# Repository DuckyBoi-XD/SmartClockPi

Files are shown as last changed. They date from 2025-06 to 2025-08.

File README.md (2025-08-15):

A Raspberry Pi Zero 2 W based smart clock with touchscreen display, environmental sensing, and internet weather integration.

## KiCad Stuff

This project uses KiCad for PCB design. The files are located in the `PCB/` directory. You can open them with KiCad to view the schematics and PCB layout. These are the screenshots of the PCB and schematics:

### PCB Design

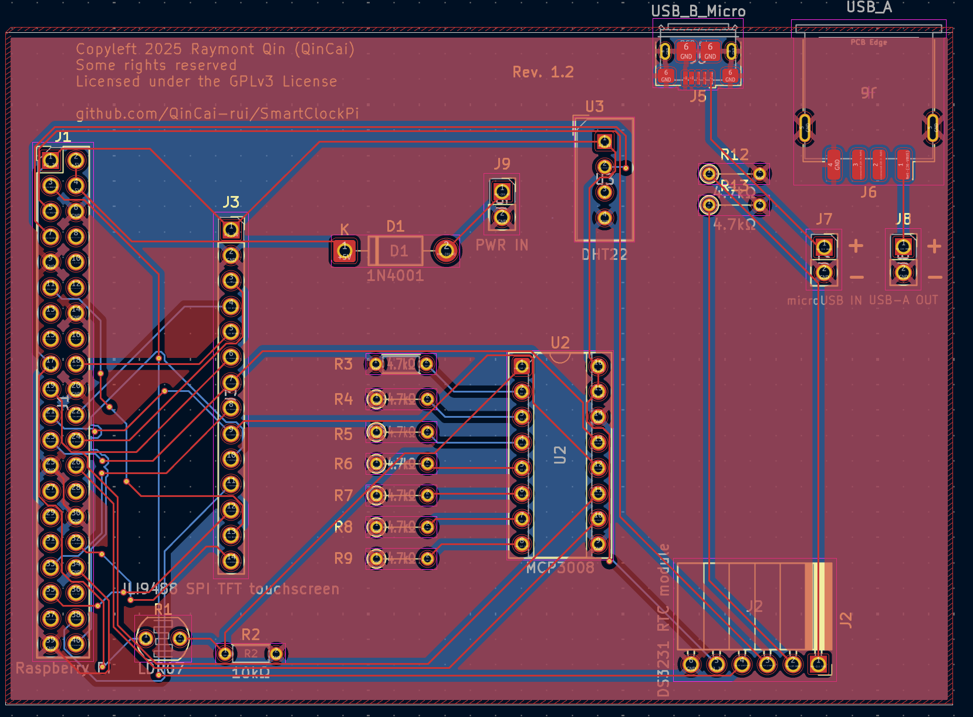
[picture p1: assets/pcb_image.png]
PCB image


### PCB rendering



### Schematics

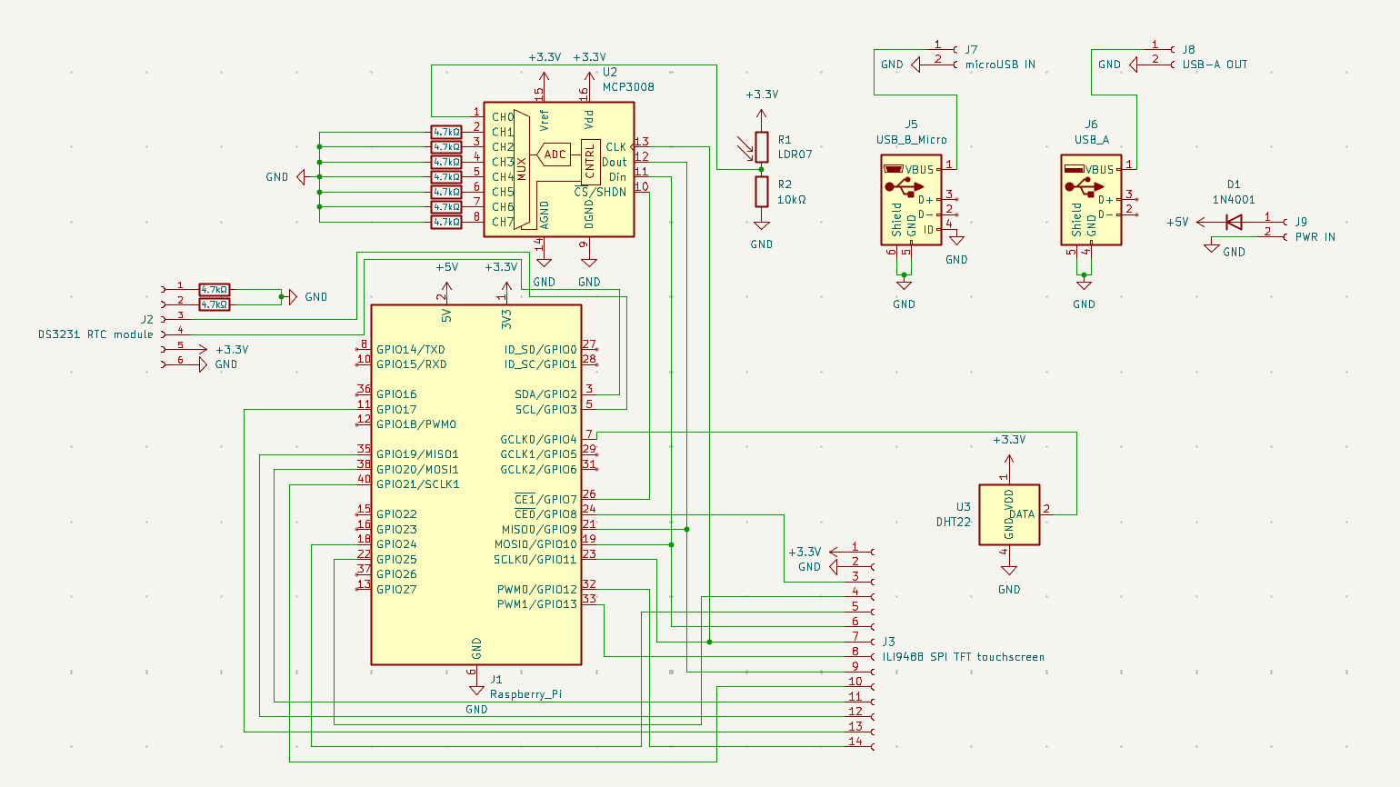
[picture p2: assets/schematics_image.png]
Schematics image


## Sketch

sketch

## CAD (case design)





## BOM (table format)

| Component | Description | Quantity | Link | Price | Shipping | Est. price (exl. GST) | Est. price (inc. GST) |
|---|---|---|---|---|---|---|---|
| Raspberry Pi Zero 2 W | Main controller/computer of the project | 1 | https://www.aliexpress.com/item/1005007899652009.html | $15.00 | $0.00 | $15.00 | $17.25 |
| ILI9488 3.5" SPI TFT Touchscreen | 480x320 pixel color LCD with resistive touch input, using SPI interface; displays the clock and all UI elements. | 1 | https://www.aliexpress.com/item/1005007096645415.html | $12.34 | $0.00 | $12.34 | $14.19 |
| DHT22 Sensor | provides indoor environmental readings | 1 | https://www.aliexpress.com/item/32759901711.html | $2.05 | $0.00 | $2.05 | $2.36 |
| 1x14 Pin Socket Header | Single-row, female 2.54mm pitch header; connects the TFT display module to the PCB. | 1 (pack of 10, use 1) | https://www.aliexpress.com/item/4001198421663.html | $1.99 | $0.00 | $1.99 | $2.29 |
| 1x6 Pin Socket Header | Single-row, female 2.54mm pitch header; connects the DAC to the PCB. | 1 (pack of 10, use 1) | https://www.aliexpress.com/item/4001198421663.html | $1.70 | $0.00 | $1.70 | $1.96 |
| 1x6 Pin Socket Header Right angled | Single-row, female 2.54mm pitch, right angle header; connects the RTC module to the PCB. | 1 (pack of 5, use 1) | https://www.aliexpress.com/item/1005008210852764.html | $1.64 | $0.00 | $1.64 | $1.89 |
| 1x4 Pin Socket Header | Single-row, female 2.54mm pitch header; connects the DHT22 to the PCB. | 1 (pack of 10, use 1) | https://www.aliexpress.com/item/4001198421663.html | $1.69 | $0.00 | $1.69 | $1.94 |
| Photoresistor | for automatic display brightness adjustment. 5528 | 1 (pack of 50, use 1) | https://www.aliexpress.com/item/1005002145052802.html | $1.66 | $1.68 | $3.34 | $3.84 |
| MCP3008 (DIP) | 8-channel, 10-bit ADC with SPI interface; reads analog sensors like photoresistors. | 3 (use 1) | https://www.digikey.co.nz/en/products/detail/microchip-technology/MCP3008-I-P/319422 | $9.36 | $0.00 | $9.36 | $10.76 |
| DS3231 RTC (module) | Real-time clock module with battery backup; keeps accurate time when Pi is powered off (or when my internet connection dies) | 1 | https://www.aliexpress.com/item/1005008172587774.html | $1.70 | $0.00 | $1.70 | $1.96 |
| DIP-16 IC socket | For MCP3008 (DIP) | 1 (pack of 10, use 1) | https://www.aliexpress.com/item/1005009030108697.html | $0.60 | $1.63 | $2.23 | $2.56 |
| LIR3032 cell | 3.6V Lithium Battery Rechargeable Battery | 1 (pack of 2, use 1) | https://www.aliexpress.com/item/1005009124669879.html | $7.17 | $0.00 | $7.17 | $8.25 |
| micro-USB port | Power input | 5 (use 1) | https://www.digikey.co.nz/en/products/detail/amphenol-cs-fci/10118193-0001LF/2785388 | $2.15 | $0.00 | $2.15 | $2.47 |
| USB-A port | Power output (from battery charger) | 5 (use 1) | https://www.digikey.co.nz/en/products/detail/gct/USB1046-GF-0190-L-B-A/10649632 | $3.65 | $0.00 | $3.65 | $4.20 |
| 18650 Lithium Battery Charger | 5V 2.4A Dual USB OUT | 1 (pack of 2, use 1) | https://www.aliexpress.com/item/1005006839030660.html | $6.77 | $0.00 | $6.77 | $7.79 |
| microSD card | 64GB | 2 (use 1) | https://www.digikey.co.nz/en/products/detail/raspberry-pi/SC1629/24627140 | $12.98 | $0.00 | $12.98 | $14.93 |
| Diode | 1N4001 | 100 | https://www.digikey.co.nz/en/products/detail/diotec-semiconductor/1N4001/13164614 | $4.66 | $0.00 | $4.66 | $5.36 |
| USB speaker |  | 1 | https://www.aliexpress.com/item/1005007586786674.html | $4.52 | $8.20 | $12.72 | $14.63 |
| **TOTAL** |  |  |  |  |  | **$103.14** | **$118.61** |

## Why I Made This

I wanted a smart clock that could display the time, date, indoor temperature, humidity, and outdoor weather conditions. I also wanted it to have a touchscreen interface for easy interaction. The Raspberry Pi Zero 2 W was chosen for its compact size and sufficient processing power for this project.

"Why don't you just buy a pre-made smart clock?" you might ask. Well, I wanted to learn more about PCB layout/designing. This project is a great way to "exercise" while creating something useful for myself.

Also, I wanted to make it modular so I can easily swap out components or add new features in the future. The custom PCB design allows for easy connections and modifications.

## Features

### Display & Interface

- **3.5" ILI9488 SPI TFT Touchscreen** (480x320 pixels)
- Resistive touch input for UI
- Large, clear font display for time and date
- Automatic brightness adjustment via photoresistor (TO-DO, once I get the parts)

### Environmental Monitoring

- **DHT22 Sensor** for indoor temperature, humidity readings
- Real-time sensor data updates

### Weather Integration

- Internet weather data from wttr.in (Auckland, Half Moon Bay area)
- No API key required
- Displays outdoor temperature, humidity, and weather status
- Update every 10 minutes

### Time & Clock Features

- **DS3231 Real-Time Clock (RTC)** with battery backup
- Maintains accurate time even when Pi is powered off (or when my internet dies)
- Large, readable time display

### Hardware Features

- Custom PCB design with modular connections (so i can unplug and replug the modules)
- Female header pins for easy module connection
- Compact form factor (94.5mm x 67.2mm PCB)

## Hardware Components

Please see [SmartClockPi-bom.csv](SmartClockPi-bom.csv) (Created since this is required for Highway)

## Software Features

- **Python-based application** using:
  - `luma.lcd` for display control
  - `adafruit-circuitpython-bme280` for sensor interface
  - `Pillow` for graphics rendering
- Real-time clock display with large, clear fonts. Need to test if this actually works
- Weather data integration from wttr.in
- Environmental sensor monitoring

## Project Structure

```txt
SmartClockPi/
├── README.md
├── JOURNAL.md                # Development journal with progress updates
├── SmartClockPi-bom.csv      # Bill of Materials
├── PCB/                      # KiCad PCB design files
│   ├── smartclockpi.kicad_pro
│   ├── smartclockpi.kicad_sch
│   ├── smartclockpi.kicad_pcb
│   └── Gerber/               # Manufacturing files
└── [Software files to be added]
```

## Acknowledgements

- Thanks to the Raspberry Pi community for their resources and other stuff.
- A HUGE shoutout to my friend, [@DuckyBoi-XD](https://github.com/DuckyBoi-XD), for designing the case/enclosure for this project, located in the `CAD/` directory.

## License

This project is Free and Open-source, licensed under the GPLv3 license. Feel free to contribute or use it for your own projects!

See [LICENSE](LICENSE) for more details.

---

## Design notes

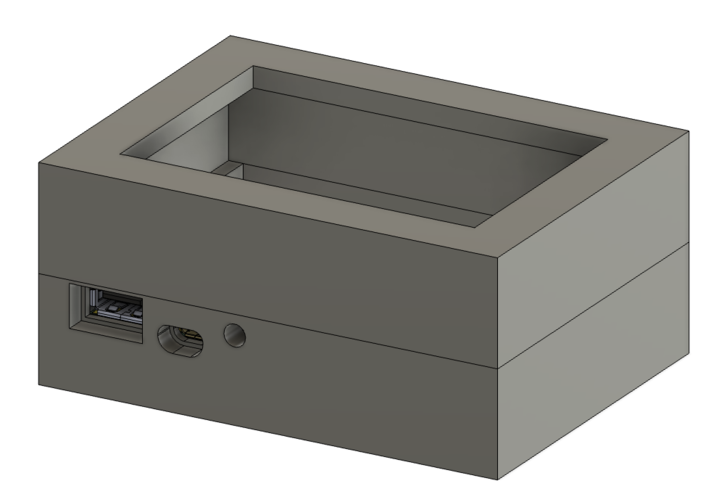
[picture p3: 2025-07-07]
assets/main_case.png

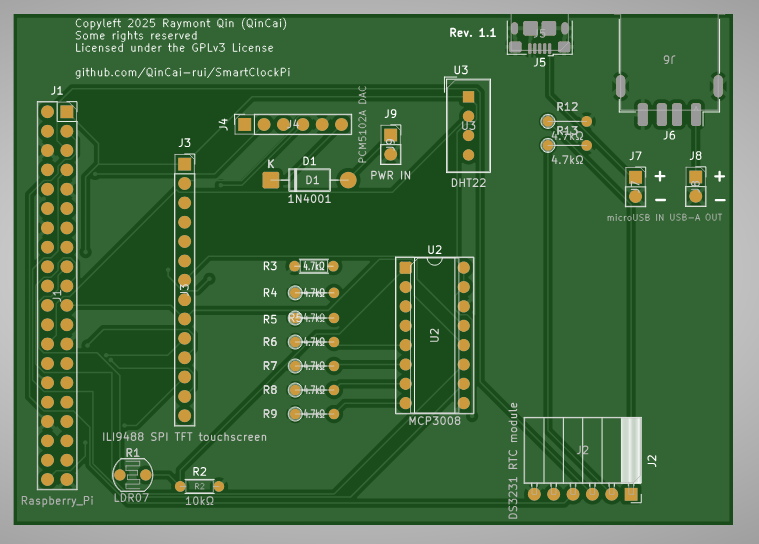
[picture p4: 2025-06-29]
assets/pcb-render.png

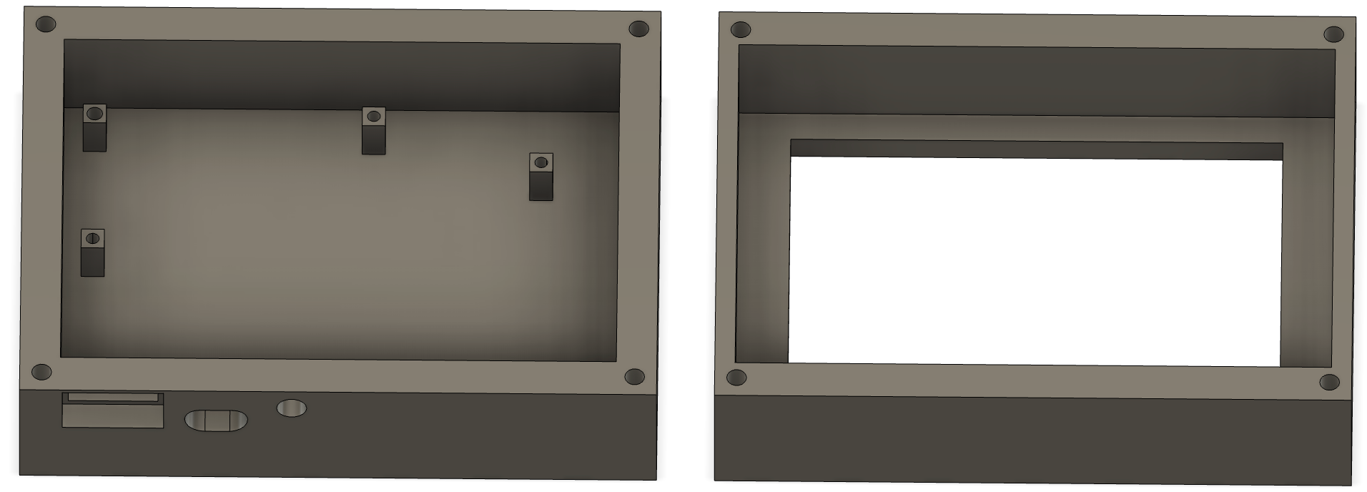
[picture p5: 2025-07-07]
assets/prod_case.png

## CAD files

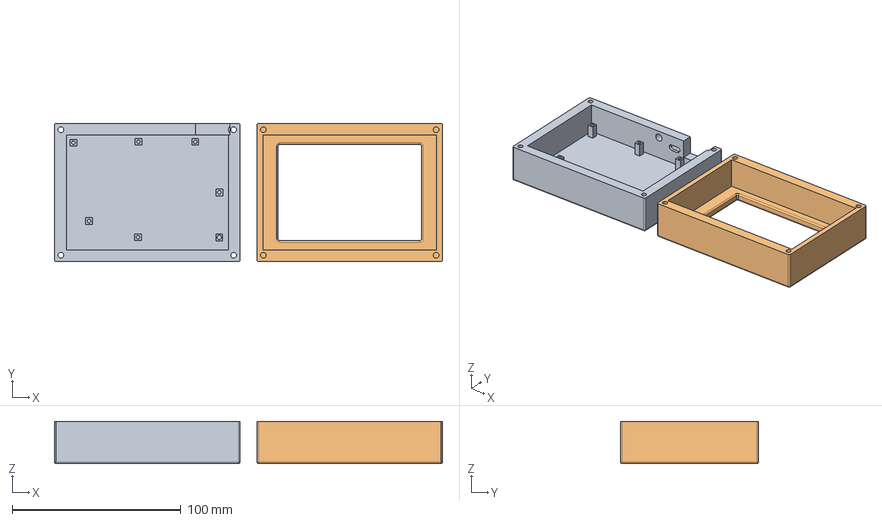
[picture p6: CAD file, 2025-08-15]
CAD/SmartPiCLOCK.step
230.0 x 82.0 x 25.0 mm

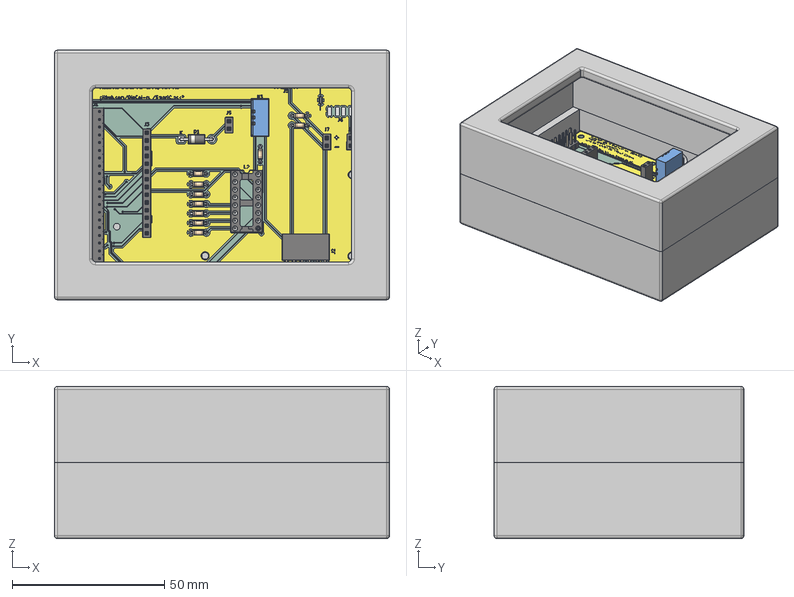
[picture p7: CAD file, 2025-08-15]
CAD/smartclockpi.step
110.0 x 82.0 x 50.0 mm
PinSocket_1x14_P2.54mm_Vertical
R_Axial_DIN0204_L3.6mm_D1.6mm_P5.08mm_Horizontal x 10
PinSocket_1x06_P2.54mm_Horizontal
D_DO-41_SOD81_P10.16mm_Horizontal
R_LDR_5.2x5.2mm_P3.5mm_Horizontal
PinSocket_1x02_P2.54mm_Vertical x 3
DIP-16_W7.62mm_Socket
PinHeader_2x20_P2.54mm_Vertical
Aosong_DHT11_5.5x12.0_P2.54mm
smartclockpi_copper
smartclockpi_pad
smartclockpi_via
smartclockpi_silkscreen
smartclockpi_PCB

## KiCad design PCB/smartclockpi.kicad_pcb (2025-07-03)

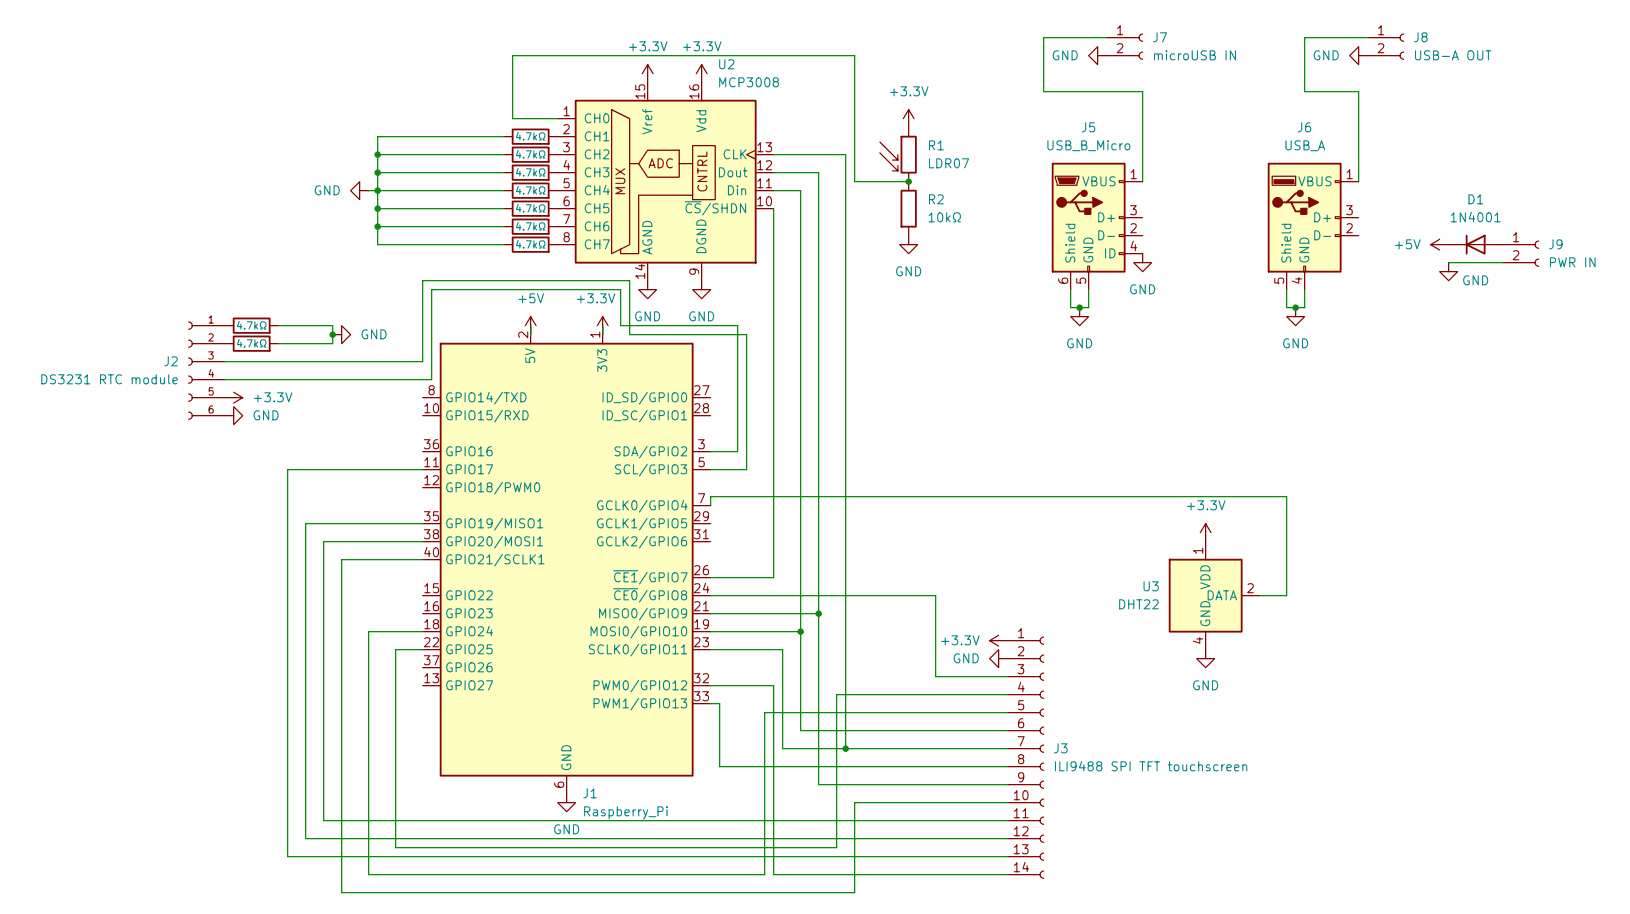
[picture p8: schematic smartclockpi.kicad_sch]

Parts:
D1: 1N4001; D_DO-41_SOD81_P10.16mm_Horizontal
J1: Raspberry_Pi; PinHeader_2x20_P2.54mm_Vertical
J2: DS3231 RTC module; PinSocket_1x06_P2.54mm_Horizontal
J3: ILI9488 SPI TFT touchscreen; PinSocket_1x14_P2.54mm_Vertical
J5: USB_B_Micro; USB_Micro-B_Amphenol_10118193-0001LF_Horizontal
J6: USB_A; USB_A_Receptacle_GCT_USB1046
J7: microUSB IN; PinSocket_1x02_P2.54mm_Vertical
J8: USB-A OUT; PinSocket_1x02_P2.54mm_Vertical
J9: PWR IN; PinSocket_1x02_P2.54mm_Vertical
R1: LDR07; R_LDR_5.2x5.2mm_P3.5mm_Horizontal
R2: 10kΩ; R_Axial_DIN0204_L3.6mm_D1.6mm_P5.08mm_Horizontal
R3, R4, R5, R6, R7, R8, R9, R12, R13: 4.7kΩ; R_Axial_DIN0204_L3.6mm_D1.6mm_P5.08mm_Horizontal
U2: MCP3008; DIP-16_W7.62mm_Socket
U3: DHT22; Aosong_DHT11_5.5x12.0_P2.54mm

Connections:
+3.3V: J1.1 (3V3), J1.17 (3V3), J2.5 (VCC), J3.1 (VCC), R1.1, U2.15 (Vref), U2.16 (Vdd), U3.1 (VDD)
+5V: D1.1 (K), J1.2 (5V), J1.4 (5V)
GND: J1.6 (GND), J1.9 (GND), J1.14 (GND), J1.20 (GND), J1.25 (GND), J1.30 (GND), J1.34 (GND), J1.39 (GND), J2.6 (GND), J3.2 (GND), J5.4 (ID), J5.5 (GND), J5.6 (Shield), J6.4 (GND), J6.5 (Shield), J7.2, J8.2, J9.2, R2.2, R3.1, R4.1, R5.1, R6.1, R7.1, R8.1, R9.1, R12.2, R13.2, U2.9 (DGND), U2.14 (AGND), U3.4 (GND)
unnamed: D1.2 (A), J9.1
unnamed: J1.7 (GCLK0/GPIO4), U3.2 (DATA)
unnamed: J1.11 (GPIO17), J3.13 (T_DO)
unnamed: J1.35 (GPIO19/MISO1), J3.12 (T_DIN)
unnamed: J1.38 (GPIO20/MOSI1), J3.11 (T_CS)
unnamed: J1.40 (GPIO21/SCLK1), J3.10 (T_CLK)
unnamed: J1.18 (GPIO24), J3.5 (DC/RS)
unnamed: J1.22 (GPIO25), J3.4 (RESET)
unnamed: J1.21 (MISO0/GPIO9), J3.9 (MISO), U2.12 (Dout)
unnamed: J1.19 (MOSI0/GPIO10), J3.6 (MOSI), U2.11 (Din)
unnamed: J1.32 (PWM0/GPIO12), J3.14 (T_IRQ)
unnamed: J1.33 (PWM1/GPIO13), J3.8 (LED)
unnamed: J1.23 (SCLK0/GPIO11), J3.7 (SCK), U2.13 (CLK)
unnamed: J1.5 (SCL/GPIO3), J2.3 (SCL)
unnamed: J1.3 (SDA/GPIO2), J2.4 (SDA)
unnamed: J1.24 (~CE0/GPIO8), J3.3 (CS)
unnamed: J1.26 (~CE1/GPIO7), U2.10 (~CS/SHDN)
unnamed: J2.1 (32K), R12.1
unnamed: J2.2 (SQW), R13.1
unnamed: J5.1 (VBUS), J7.1
unnamed: J6.1 (VBUS), J8.1
unnamed: R1.2, R2.1, U2.1 (CH0)
unnamed: R3.2, U2.2 (CH1)
unnamed: R4.2, U2.3 (CH2)
unnamed: R5.2, U2.4 (CH3)
unnamed: R6.2, U2.5 (CH4)
unnamed: R7.2, U2.6 (CH5)
unnamed: R8.2, U2.7 (CH6)
unnamed: R9.2, U2.8 (CH7)

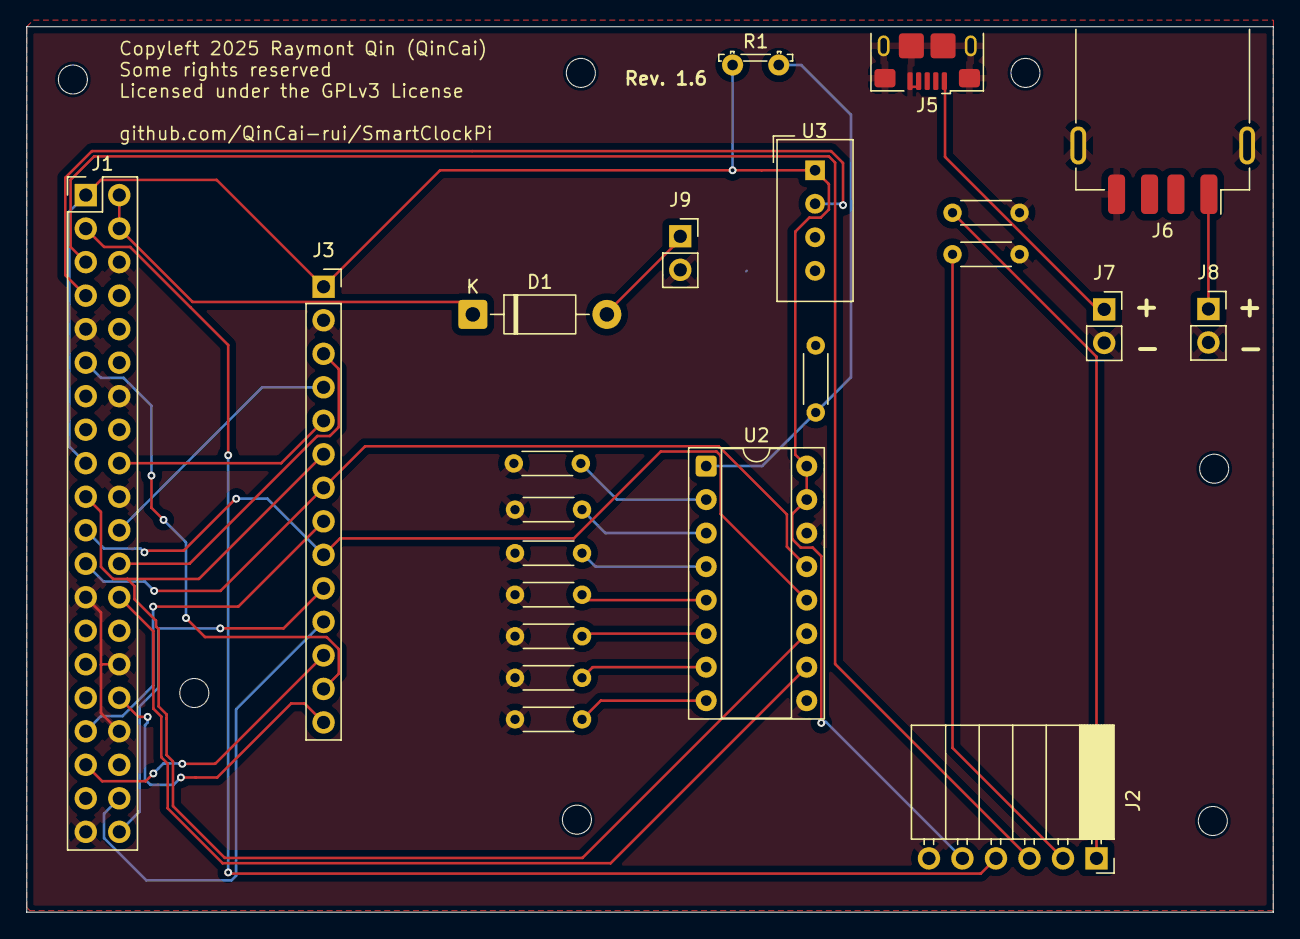
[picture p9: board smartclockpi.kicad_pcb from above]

Board: 2 copper layers, 94.5 x 67.1 mm, 22 parts (0 on the bottom side), 32 nets.

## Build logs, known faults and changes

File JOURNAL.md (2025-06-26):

---
title: "SmartClockPi"
author: "@QinCai-rui"
description: "A Raspberry Pi Zero 2 W based smart clock with touchscreen, environmental sensing, and more."
created_at: "2025-06-09"
---

Time spent on this project: **~35 hours**

## 8/6/25

### Update 1

Started a new project for a smart clock using the Raspberry Pi Zero 2 W.

**Planning:**

- Decided on a feature set: large touchscreen display, temperature/humidity/pressure monitoring, internet weather, touch sensing, and music playback for the alarm part.
- Researched and compared display modules -- settled on a [3.5" ILI9488 SPI TFT resistive touchscreen (480x320)](https://www.aliexpress.com/item/1005007096645415.html). Good size and clarity.
- Chose the [BME280 sensor](https://www.aliexpress.com/item/1005004527984343.html) for environmental data, using the I2C interface with the Pi and freeing SPI for the display.
- Support for both devices with available Python libraries (`luma.lcd`, `Pillow`, `adafruit-circuitpython-bme280`). (at least I hope so)

**Links:**  

- [3.5" ILI9488 SPI TFT Touch Display](https://www.aliexpress.com/item/1005007096645415.html)  
- [BME280 I2C/SPI Sensor Module](https://www.aliexpress.com/item/1005004527984343.html)

**Hardware & Wiring:**  
Used the pinout provided in the datasheet for the display:

Screenshot 2025-06-09 at 7 57 09 AM

The BME280:

Screenshot 2025-06-09 at 7 57 27 AM

#### SPI Display Pins (ILI9488)

| Pin | Name | Description | Raspberry Pi Zero 2 W Pin |
|-----|---|---|---|
| 1 | VCC | 5V/3.3V power input | 3.3V (Pin 1 or 17) |
| 2 | GND | grounding | GND (Pin 6 or 9) |
| 3 | CS | LCD chip select signal, low level enable | GPIO8 (SPI0_CE0, Pin 24) |
| 4 | RESET | LCD reset signal, low level reset | GPIO25 (Pin 22) |
| 5 | DC/RS | LCD register/data selection signal | GPIO24 (Pin 18) |
| 6 | SDI(MOSI) | SPI bus write data signal | GPIO10 (SPI0_MOSI, Pin 19)  |
| 7 | SCK | SPI bus clock signal | GPIO11 (SPI0_SCLK, Pin 23)  |
| 8 | LED | Backlight control (tie to 3.3V for always on)  | 3.3V (Pin 1 or 17) |
| 9 | SDO(MISO) | SPI bus read data signal (optional) | GPIO9 (SPI0_MISO, Pin 21) |

#### Touch Panel Pins (using touch, XPT2046 controller)

| Pin  | Name | Description | Raspberry Pi GPIO (need to work this out later) |
|---|---|---|---|
| 10 | T_CLK  | Touch SPI bus clock signal | Any free GPIO  |
| 11 | T_CS | Touch chip select (active low) | Any free GPIO |
| 12 | T_DIN  | Touch SPI input | Any free GPIO |
| 13 | T_DO | Touch SPI output | Any free GPIO |
| 14 | T_IRQ  | Touch interrupt (active low) | Any free GPIO |

#### BME280 Sensor (I2C)

| Pin  | Name | Description | Raspberry Pi Zero 2 W Pin |
|---|---|---|---|
| 1 | VCC  | 3.3V power | 3.3V (Pin 1 or 17) |
| 2 | GND  | Ground | GND (Pin 6 or 9) |
| 3 | SDA  | I2C data | GPIO2 (I2C SDA, Pin 3) |
| 4 | SCL  | I2C clock | GPIO3 (I2C SCL, Pin 5) |

- Both modules use 3.3V power (chose BME-3.3, so do NOT use 5V).
- LED pin on display can be tied to 3.3V for always-on backlight, or controlled by a PWM GPIO for dimming.

**TO_DO**

- add a photoresistor or something to chnage the bightness dynamically

Time spent today: **2 hours** (research, planning, reviewing libraries, looking for modules, and mapping out wiring)

---

## 10/6/25

### Update 2

Worked on SmartClockPi code and UI, even though I don't have the hardware yet.

**Today:**

- Wrote the main Python app logic for the clock display and sensor/weather integration.
- Used the `luma.lcd` library for the ILI9488 SPI display, and `adafruit-circuitpython-bme280` for the sensor interface.
- Integrated free weather data from wttr.in for Auckland, Half Moon Bay area (no API key required).
- The app will show:  
  - Real time and date (large, clear fonts)
  - Indoor temperature, humidity, and pressure (from BME280, once connected)
  - Outdoor weather: main status, temperature, humidity, and icon (from wttr.in)
- Weather auto-refreshes every 10 minutes, sensor data every second.
- Alarm logic is removed for now to keep the code simple.
- All code is structured to be ready for testing as soon as the display and sensors are available.
- Next steps: add touch UI, dynamic backlight (photoresistor), and maybe a settings menu.

Time spent this session: **1.5 hours**

---

### Update 3

I started working on the schematic for the project. I wanted to include both the Raspberry Pi header, the BME280 sensor, and the ILI9488 touchscreen display in my design. However, I ran into an issue: I couldn't find a suitable symbol or footprint for the LCD screen I’m using (the ILI9488 SPI TFT touchscreen) in my KiCad’s library.

I decided to use generic header pins to represent the LCD screen in the schematic. This way, I was able to clearly show all of the required connections for the display, including the SPI and touch controller signals, power, and backlight control.

The LCD

When i get the PCB, I will just solder some female header pins (1x14) onto the board, and plug the screen in. I might need some standoffs though...

Screenshot 2025-06-10 at 4 03 51 PM

Next step: add in a photoresistor

Time spent this session: **3 hours**

---

## 11/6/25

### Update 4

I finalised my schematic during the session. The main challenge is to find the footprints and symbols for my parts. I ended up using female header pins to plug my modules in.

Screenshot 2025-06-13 at 2 10 22 PM

Time spent this session: **5 hours**

---

## 12/6/25

### Update 5

Started working on the PCB. It was very stupid converting the schematics into PCB. The `Tools > Update PCB from schematics` was greyed out. But somehow I made it work after wasting a lot of time...

Screenshot 2025-06-13 at 2 14 14 PM

Time spent this session: **4 hours**

---

## 14/5/25 & 15/5/25

### Update 6

Started sourcing the parts and organising them into a spreadsheet/Excel document



(note there are a lot of mistakes - 16/6/25)

---

## 13/5/25 & 16/5/25

### Update 7

Did a lot of work on the PCB. I connected all my 17 parts (at the time of writing) together. The big, main issue I had was to get the blue "wires" (connector lines) to show up on some of the parts. Turned out KiCad didn't know which pins were which, so it ignored them. I changed the pin numbers from correct ones to lables, replacing the numbers, since I couldn't make the lables show up before. So I changed the pin numbers back, and YAY!!




The PCB is done, so long as I don't decide to drop a few more parts in....

Time spent this session: **6 hours**

---

## 17/5/25

### Update 8

Added my parts to my BOM. I started to source some of the parts, including the Raspberry Pi Zero 2 ($25 before, now $15!!)
Screenshot 2025-06-18 at 5 00 41 PM

Time spent this session: **1.5 hours**

---

## 18/5/25

### Update 9

For this session, I worked more on the PCB. Unfortunately, I did change the PCB layout to make way for the USB connectors. The connectors are for the Li-ion battery charger module. Since there is an extra USB output, I connected it to the PCB, providing 2.4A at 5V QC.

Screenshot 2025-06-18 at 5 03 47 PM

Screenshot 2025-06-18 at 5 03 28 PM

Sourcing the USB ports was very annoying, especially with the microUSB ports (there are so many different kinds!!)

Time spent this session: **2.5 hours**

---

## 19/5/25 - 24/5/25

### Update 10

I tried to finallise sourcing the parts for my project.

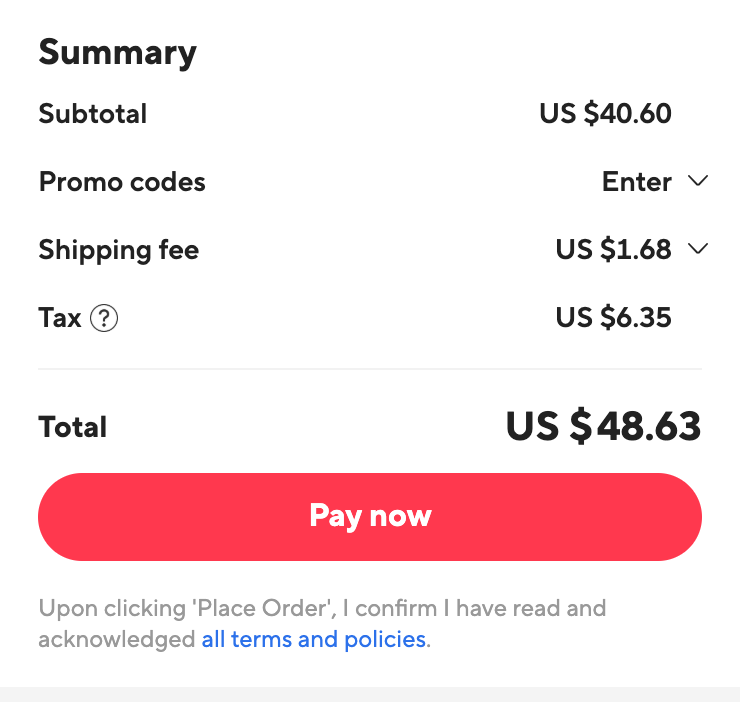
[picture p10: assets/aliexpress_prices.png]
AliExpress

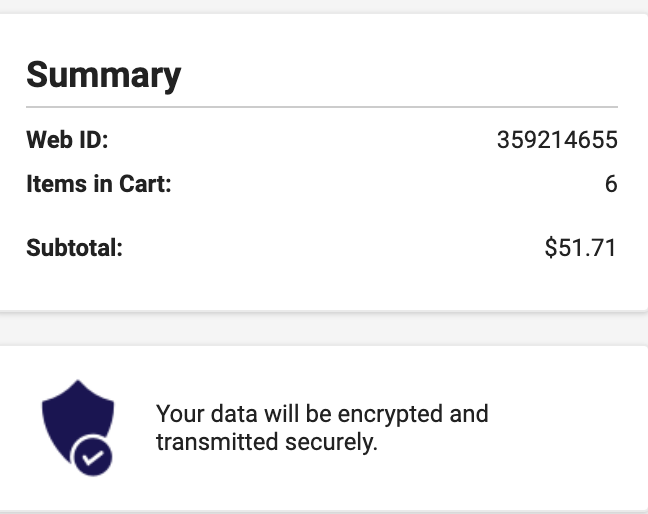
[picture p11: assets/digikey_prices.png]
Digikey


Time spent this session: **7 hours**

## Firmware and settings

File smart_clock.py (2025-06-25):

import time
from datetime import datetime
from PIL import Image, ImageDraw, ImageFont
from luma.core.interface.serial import spi
from luma.lcd.device import ili9488

import board
import adafruit_bme280
import requests

# --- INIT HARDWARE --
serial = spi(port=0, device=0, gpio_DC=24, gpio_RST=25, bus_speed_hz=48000000)
device = ili9488(serial, width=480, height=320, rotate=0)

i2c = board.I2C()
bme280 = adafruit_bme280.Adafruit_BME280_I2C(i2c)


font_large = ImageFont.truetype("/usr/share/fonts/truetype/dejavu/DejaVuSans.ttf", 80)
font_medium = ImageFont.truetype("/usr/share/fonts/truetype/dejavu/DejaVuSans.ttf", 40)
font_small = ImageFont.truetype("/usr/share/fonts/truetype/dejavu/DejaVuSans.ttf", 24)
font_tiny = ImageFont.truetype("/usr/share/fonts/truetype/dejavu/DejaVuSans.ttf", 18)

# --- WEATHER (no API key) ---
def fetch_wttr_weather():
    try:
        # "Half Moon Bay, Auckland" - returns JSON
        url = "https://wttr.in/Half%20Moon%20Bay%20Auckland?format=j1"
        resp = requests.get(url, timeout=5)
        data = resp.json()
        current = data['current_condition'][0]
        weather = {
            "status": current['weatherDesc'][0]['value'],
            "temp_C": float(current['temp_C']),
            "humidity": int(current['humidity']),
            "icon_url": current.get('weatherIconUrl', [{}])[0].get('value', None)
        }
        return weather
    except Exception:
        return None

# --- Main UI loop ---
last_weather_refresh = 0
weather_data = None

def main():
    now = datetime.now()
    time_str = now.strftime("%H:%M:%S")
    date_str = now.strftime("%a, %b %d %Y")

    # --- BME280 ---
    temperature = bme280.temperature
    humidity = bme280.humidity
    pressure = bme280.pressure

    # --- Weather fetch / 10 mins ---
    if time.time() - last_weather_refresh > 600 or not weather_data:
        wd = fetch_wttr_weather()
        if wd:
            weather_data = wd
        last_weather_refresh = time.time()

    # --- Weather icon ---
    weather_status = weather_data['status'] if weather_data else "No data"
    weather_temp = weather_data['temp_C'] if weather_data else None
    weather_hum = weather_data['humidity'] if weather_data else None
    weather_icon_url = weather_data['icon_url'] if weather_data else None

    # --- Draw UI ---
    image = Image.new("RGB", (480, 320), "black")
    draw = ImageDraw.Draw(image)

    # Draw time & date
    draw.text((30, 30), time_str, font=font_large, fill="white")
    draw.text((35, 120), date_str, font=font_medium, fill="lightgray")

    # Draw local BME280 temp/humidity/pressure
    temp_str = f"Indoor: {temperature:.1f}°C"
    hum_str = f"Humidity: {humidity:.0f}%"
    pres_str = f"Pressure: {pressure:.0f} hPa"
    draw.text((30, 180), temp_str, font=font_small, fill="orange")
    draw.text((30, 210), hum_str, font=font_small, fill="skyblue")
    draw.text((30, 240), pres_str, font=font_small, fill="yellow")

    # Draw weather (real, outdoor)
    draw.text((350, 30), "Wttr.in:", font=font_small, fill="white")
    if weather_icon_url:
        try:
            from io import BytesIO
            icon_resp = requests.get(weather_icon_url, timeout=3)
            icon_img = Image.open(BytesIO(icon_resp.content)).convert("RGBA").resize((64,64))
            image.paste(icon_img, (355, 60), icon_img)
        except Exception:
            pass
    draw.text((350, 130), f"{weather_status}", font=font_tiny, fill="yellow")
    if weather_temp is not None:
        draw.text((350, 150), f"{weather_temp:.1f}°C", font=font_small, fill="orange")
    if weather_hum is not None:
        draw.text((350, 180), f"{weather_hum:.0f}%", font=font_small, fill="skyblue")

    # Draw separator
    draw.line([(0, 270), (480, 270)], fill="gray", width=2)
    draw.text((10, 280), "Touch screen features coming soon | Ctrl+C to exit.", font=font_tiny, fill="gray")

    # Display the image
    device.display(image)

    time.sleep(1)

if __main__ == "main":
    while True:
        main()

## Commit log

2025-06-10 another update-working on schematics
2025-06-13 add schematics and pcb
    [smartclockpi.kicad_pcb, smartclockpi.kicad_sch]
2025-06-16 finallise pcb. spent toooo much time on this...
    [smartclockpi.kicad_pcb, smartclockpi.kicad_sch]
2025-06-17 update pcb
    [smartclockpi.kicad_pcb]
2025-06-17 update pcb. idk what i did
    [smartclockpi.kicad_pcb]
2025-06-18 add in usb ports
    [smartclockpi.kicad_pcb, smartclockpi.kicad_sch]
2025-06-18 add 3d model of PCB
2025-06-18 add gerber files
    [smartclockpi-B_Adhesive.gbr, smartclockpi-B_Courtyard.gbr, smartclockpi-B_Cu.gbr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]
2025-06-19 add BOM
    [SmartClockPi-bom.csv]
2025-06-24 update pcb and stuff
    [smartclockpi.kicad_pcb, smartclockpi.kicad_sch]
2025-06-26 update BOM
    [SmartClockPi-bom.csv]
2025-06-26 update kicad stuff
    [smartclockpi.kicad_sch]
2025-06-29 add pcb rendering
2025-06-30 update readme to include table format BOM
2025-07-02 modify pcb
    [smartclockpi-B_Cu.gbr, smartclockpi-B_Mask.gbr, smartclockpi-B_Paste.gbr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]
2025-07-02 update gerber zip
2025-07-02 update gerber to include drill
    [smartclockpi-B_Cu.gbr, smartclockpi-B_Mask.gbr, smartclockpi-B_Paste.gbr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]
2025-07-02 add drl
    [smartclockpi-NPTH.drl, smartclockpi-PTH.drl]
2025-07-02 update Gerber
    [smartclockpi-B_Adhesive.gbr, smartclockpi-B_Courtyard.gbr, smartclockpi-B_Cu.gbr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]
2025-07-02 fix resistor positions
    [smartclockpi-B_Cu.gbr, smartclockpi-B_Mask.gbr, smartclockpi-B_Paste.gbr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]
2025-07-03 fix PCB issues and re-gen everything needed
    [smartclockpi-B_Cu.gbr, smartclockpi-B_Mask.gbr, smartclockpi-B_Paste.gbr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]
2025-07-03 fix some DRC errors. regen models
    [smartclockpi-B_Cu.gbr, smartclockpi-B_Mask.gbr, smartclockpi-B_Paste.gbr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]
2025-07-03 update footprint for LDR. re-gen models
    [smartclockpi-B_Cu.gbr, smartclockpi-B_Mask.gbr, smartclockpi-B_Paste.gbr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]
2025-07-03 add ziped gerbers
2025-07-06 create CAD folder
2025-07-07 rename CAD files
    [main_case.step, print_case.step]
2025-07-07 add images of case

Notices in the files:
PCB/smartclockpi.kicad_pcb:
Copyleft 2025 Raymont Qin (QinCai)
